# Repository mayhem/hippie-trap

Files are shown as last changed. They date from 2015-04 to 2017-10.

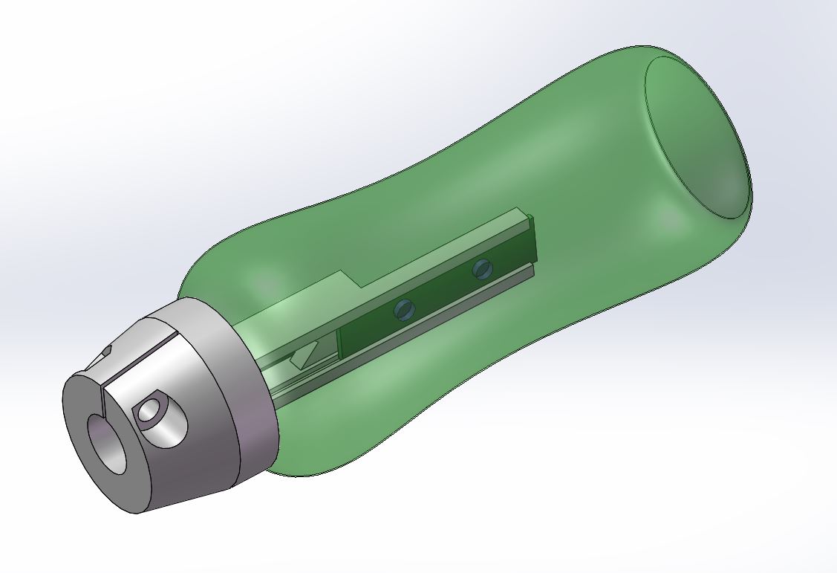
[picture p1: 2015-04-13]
design/bottle-light-assembly-1.jpg

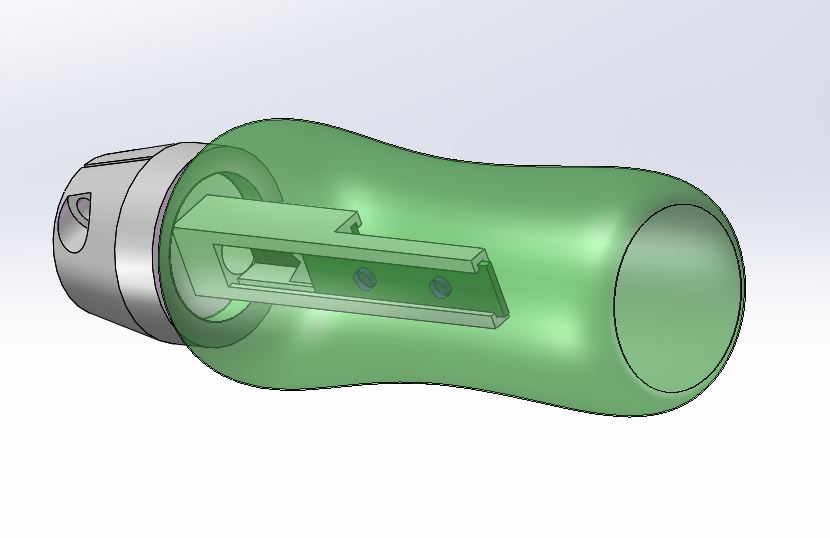
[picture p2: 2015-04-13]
design/bottle-light-assembly-2.jpg

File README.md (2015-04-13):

# led-chandelier
LED bottle chandelier built for Nowhere 2015

by Robert Kaye and David Martin

Mock-up
=======

For a render of what we think this might look like a look in the design folder.

Hardware notes
==============

The chandalier made up of about 100 bottles that will have circuit boards with LEDs
inside them. 4 RGD LEDs (WS2812B) connected to an atmega128 will light up each bottle.
Communication happens over a bone simple serial connection, hopefully at 250kbps.
For serial timing and ram reasons, I chose the atmega128 over the attiny84.

The bottles will be connected to 5V power, ground and a communication line. The communication
will be via a line driver that broadcasts the serial signal to each bottle. The RPi can then
send either color information to each bottle or more interestingly send a crude set of instructions
on how to build a color animation. This way the chanelier can work in a centrally coordinated
mode or each bottle carrying out its own program.

.brd and .sch files for Eagle are in hardware folder.

Notes about the circuit
-----------------------

- Regulated 5V power supply in the body of the chandelier
- WS2812B LEDS: http://www.adafruit.com/datasheets/WS2812B.pdf
- MCU: atmega168
- Shottky diodes on the inputs.
- Program via a pogoplug, no actual connector will be on the board.

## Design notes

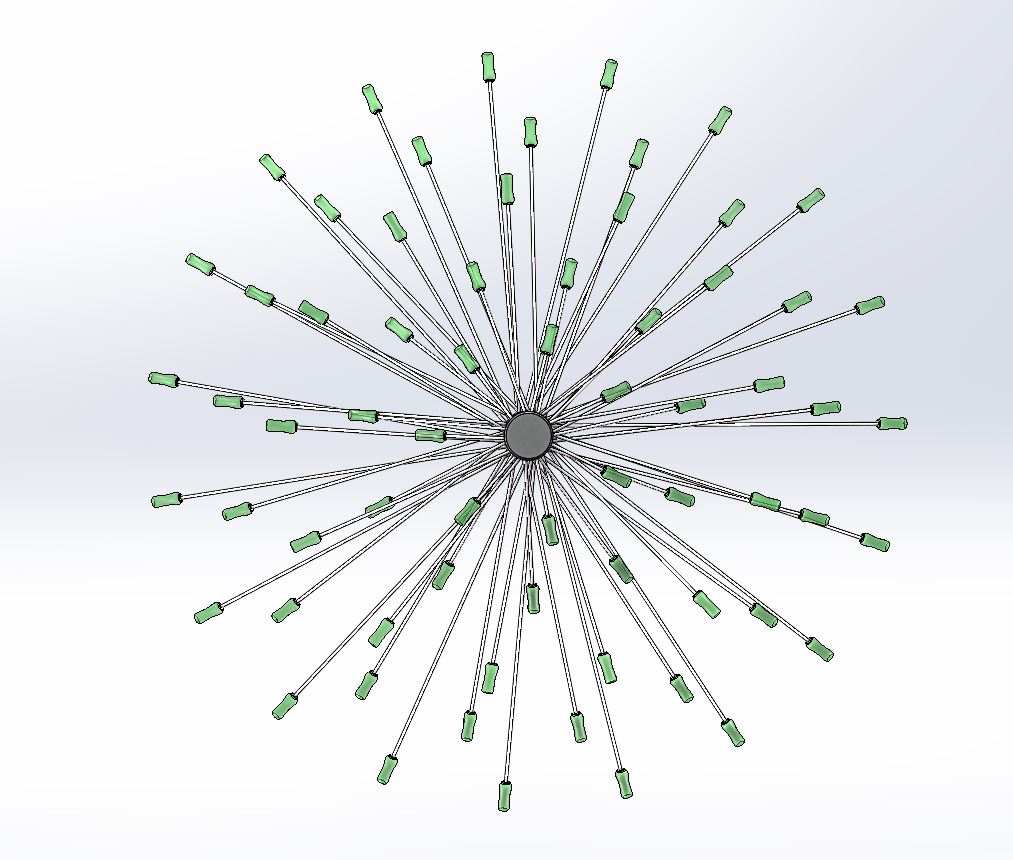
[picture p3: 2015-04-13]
design/chandelier-bottom-view.jpg

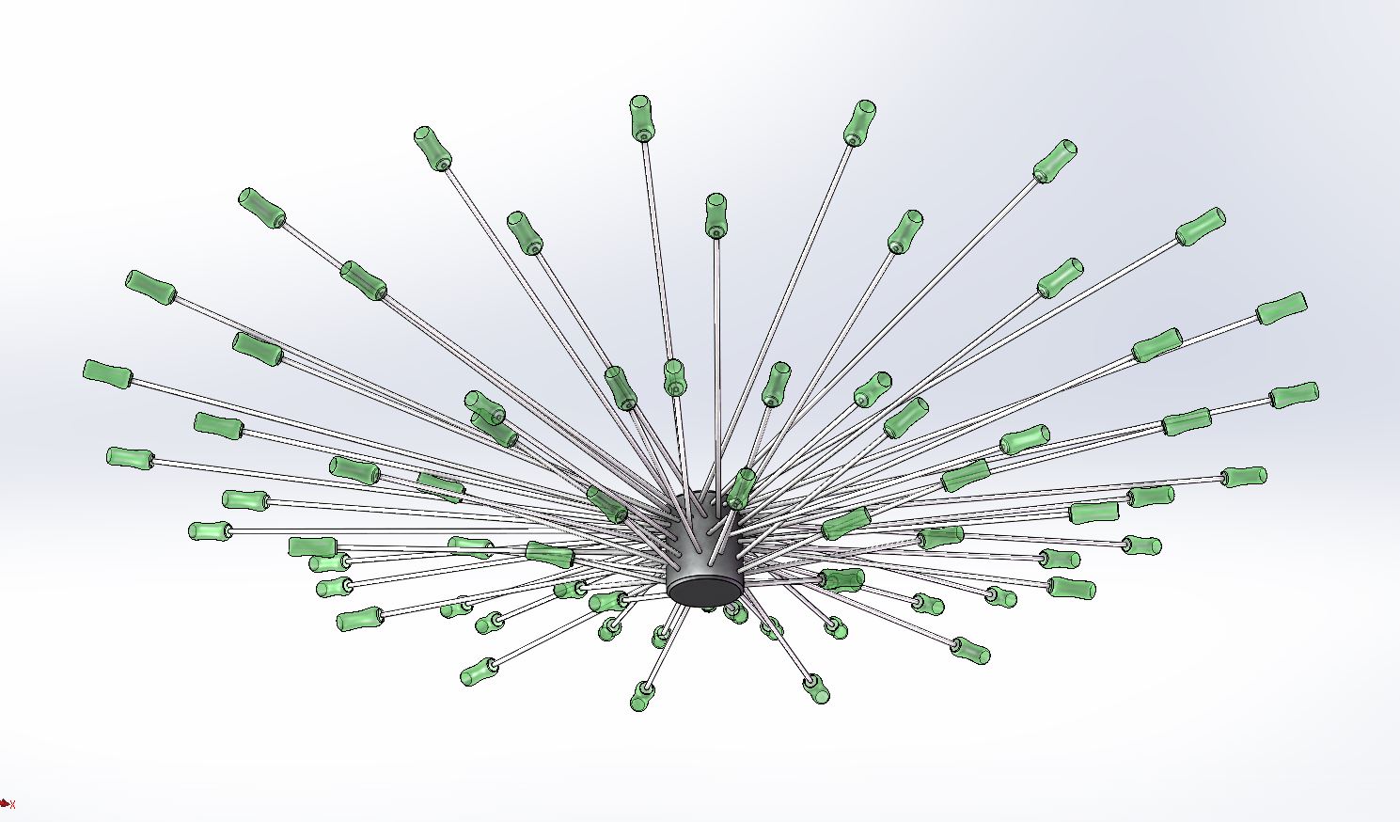
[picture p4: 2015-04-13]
design/chandelier-perspective-view.jpg

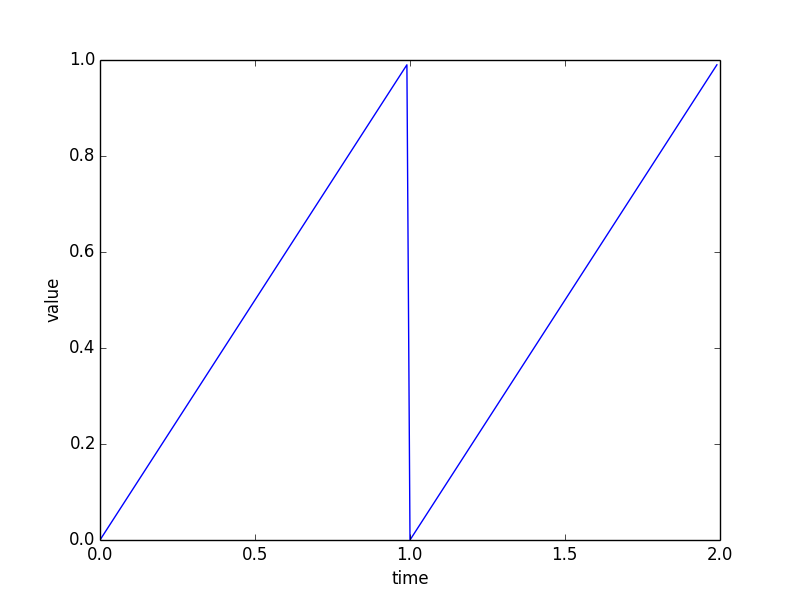
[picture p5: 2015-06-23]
graphs/sawtooth.png

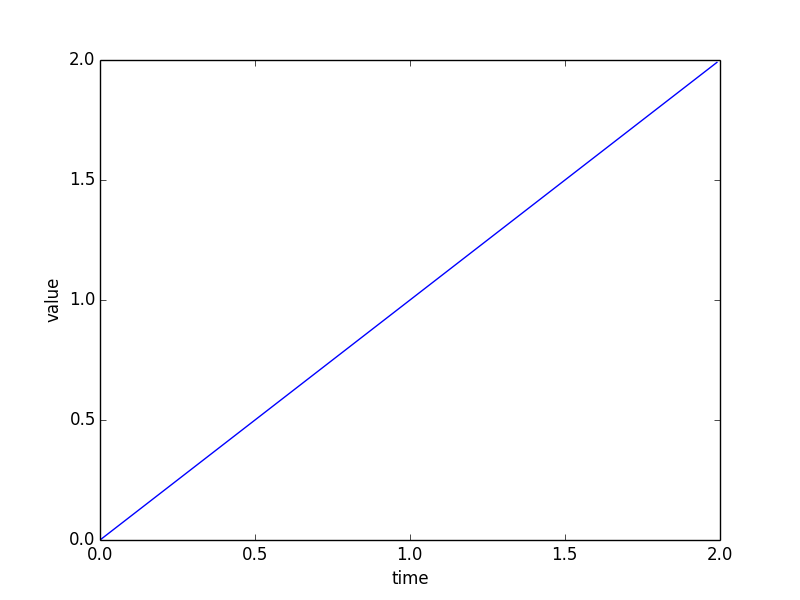
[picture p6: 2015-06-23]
graphs/line.png

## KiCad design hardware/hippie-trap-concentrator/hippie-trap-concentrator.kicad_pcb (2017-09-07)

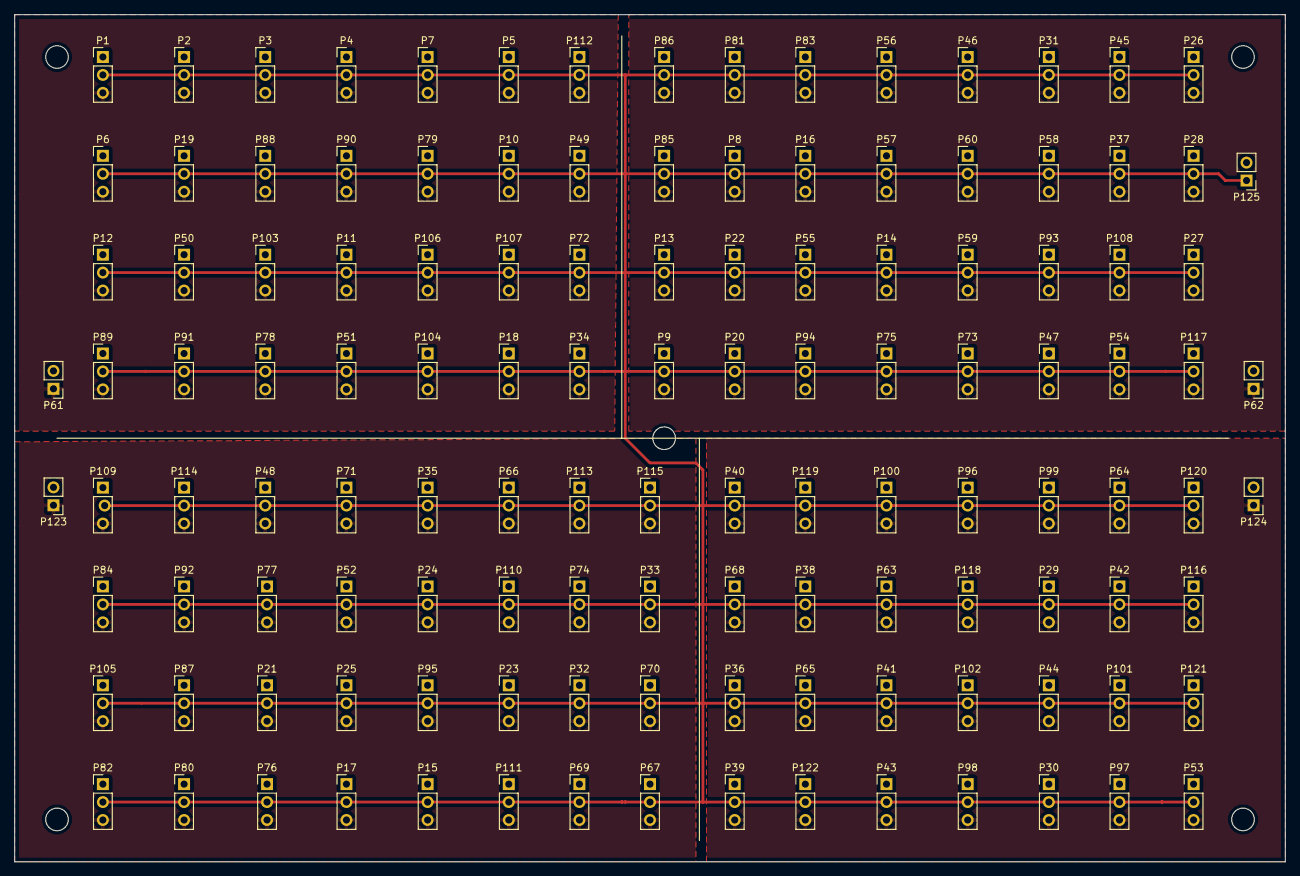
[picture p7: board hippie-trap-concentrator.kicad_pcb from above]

Board: 2 copper layers, 180.0 x 120.0 mm, 125 parts (0 on the bottom side), 3 nets.

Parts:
P1, P2, P3, P4, P5, P6, P7, P8, P9, P10, P11, P12, P13, P14, P15, P16, P17, P18, P19, P20, P21, P22, P23, P24, P25, P26, P27, P28, P29, P30, P31, P32, P33, P34, P35, P36, P37, P38, P39, P40, P41, P42, P43, P44, P45, P46, P47, P48, P49, P50, P51, P52, P53, P54, P55, P56, P57, P58, P59, P60, P63, P64, P65, P66, P67, P68, P69, P70, P71, P72, P73, P74, P75, P76, P77, P78, P79, P80, P81, P82, P83, P84, P85, P86, P87, P88, P89, P90, P91, P92, P93, P94, P95, P96, P97, P98, P99, P100, P101, P102, P103, P104, P105, P106, P107, P108, P109, P110, P111, P112, P113, P114, P115, P116, P117, P118, P119, P120, P121, P122: CONN_01X03; Pin_Header_Straight_1x03_Pitch2.54mm
P61: PWR1; Pin_Header_Straight_1x02_Pitch2.54mm
P62: PWR2; Pin_Header_Straight_1x02_Pitch2.54mm
P123: PWR3; Pin_Header_Straight_1x02_Pitch2.54mm
P124: PWR4; Pin_Header_Straight_1x02_Pitch2.54mm
P125: RPi; Pin_Header_Straight_1x02_Pitch2.54mm

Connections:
/5V: P1.3, P2.3, P3.3, P4.3, P5.3, P6.3, P7.3, P8.3, P9.3, P10.3, P11.3, P12.3, P13.3, P14.3, P15.3, P16.3, P17.3, P18.3, P19.3, P20.3, P21.3, P22.3, P23.3, P24.3, P25.3, P26.3, P27.3, P28.3, P29.3, P30.3, P31.3, P32.3, P33.3, P34.3, P35.3, P36.3, P37.3, P38.3, P39.3, P40.3, P41.3, P42.3, P43.3, P44.3, P45.3, P46.3, P47.3, P48.3, P49.3, P50.3, P51.3, P52.3, P53.3, P54.3, P55.3, P56.3, P57.3, P58.3, P59.3, P60.3, P61.1, P62.1, P63.3, P64.3, P65.3, P66.3, P67.3, P68.3, P69.3, P70.3, P71.3, P72.3, P73.3, P74.3, P75.3, P76.3, P77.3, P78.3, P79.3, P80.3, P81.3, P82.3, P83.3, P84.3, P85.3, P86.3, P87.3, P88.3, P89.3, P90.3, P91.3, P92.3, P93.3, P94.3, P95.3, P96.3, P97.3, P98.3, P99.3, P100.3, P101.3, P102.3, P103.3, P104.3, P105.3, P106.3, P107.3, P108.3, P109.3, P110.3, P111.3, P112.3, P113.3, P114.3, P115.3, P116.3, P117.3, P118.3, P119.3, P120.3, P121.3, P122.3, P123.1, P124.1
/DATA: P1.2, P2.2, P3.2, P4.2, P5.2, P6.2, P7.2, P8.2, P9.2, P10.2, P11.2, P12.2, P13.2, P14.2, P15.2, P16.2, P17.2, P18.2, P19.2, P20.2, P21.2, P22.2, P23.2, P24.2, P25.2, P26.2, P27.2, P28.2, P29.2, P30.2, P31.2, P32.2, P33.2, P34.2, P35.2, P36.2, P37.2, P38.2, P39.2, P40.2, P41.2, P42.2, P43.2, P44.2, P45.2, P46.2, P47.2, P48.2, P49.2, P50.2, P51.2, P52.2, P53.2, P54.2, P55.2, P56.2, P57.2, P58.2, P59.2, P60.2, P63.2, P64.2, P65.2, P66.2, P67.2, P68.2, P69.2, P70.2, P71.2, P72.2, P73.2, P74.2, P75.2, P76.2, P77.2, P78.2, P79.2, P80.2, P81.2, P82.2, P83.2, P84.2, P85.2, P86.2, P87.2, P88.2, P89.2, P90.2, P91.2, P92.2, P93.2, P94.2, P95.2, P96.2, P97.2, P98.2, P99.2, P100.2, P101.2, P102.2, P103.2, P104.2, P105.2, P106.2, P107.2, P108.2, P109.2, P110.2, P111.2, P112.2, P113.2, P114.2, P115.2, P116.2, P117.2, P118.2, P119.2, P120.2, P121.2, P122.2, P125.1
/GND: P1.1, P2.1, P3.1, P4.1, P5.1, P6.1, P7.1, P8.1, P9.1, P10.1, P11.1, P12.1, P13.1, P14.1, P15.1, P16.1, P17.1, P18.1, P19.1, P20.1, P21.1, P22.1, P23.1, P24.1, P25.1, P26.1, P27.1, P28.1, P29.1, P30.1, P31.1, P32.1, P33.1, P34.1, P35.1, P36.1, P37.1, P38.1, P39.1, P40.1, P41.1, P42.1, P43.1, P44.1, P45.1, P46.1, P47.1, P48.1, P49.1, P50.1, P51.1, P52.1, P53.1, P54.1, P55.1, P56.1, P57.1, P58.1, P59.1, P60.1, P61.2, P62.2, P63.1, P64.1, P65.1, P66.1, P67.1, P68.1, P69.1, P70.1, P71.1, P72.1, P73.1, P74.1, P75.1, P76.1, P77.1, P78.1, P79.1, P80.1, P81.1, P82.1, P83.1, P84.1, P85.1, P86.1, P87.1, P88.1, P89.1, P90.1, P91.1, P92.1, P93.1, P94.1, P95.1, P96.1, P97.1, P98.1, P99.1, P100.1, P101.1, P102.1, P103.1, P104.1, P105.1, P106.1, P107.1, P108.1, P109.1, P110.1, P111.1, P112.1, P113.1, P114.1, P115.1, P116.1, P117.1, P118.1, P119.1, P120.1, P121.1, P122.1, P123.2, P124.2, P125.2

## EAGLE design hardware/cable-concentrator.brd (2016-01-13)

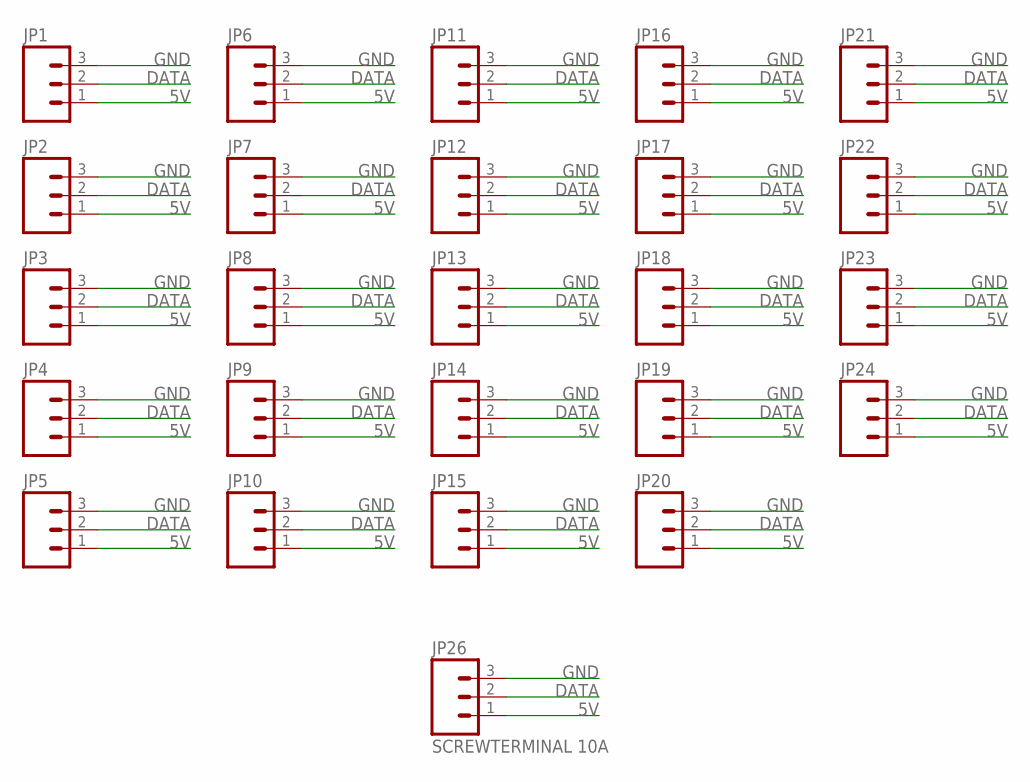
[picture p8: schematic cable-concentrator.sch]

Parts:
JP1, JP2, JP3, JP4, JP5, JP6, JP7, JP8, JP9, JP10, JP11, JP12, JP13, JP14, JP15, JP16, JP17, JP18, JP19, JP20, JP21, JP22, JP23, JP24: M03PTH; 1X03
JP26: SCREWTERMINAL 10A; SCREWTERMINAL-3.5MM-3

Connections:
5V: JP1.1, JP2.1, JP3.1, JP4.1, JP5.1, JP6.1, JP7.1, JP8.1, JP9.1, JP10.1, JP11.1, JP12.1, JP13.1, JP14.1, JP15.1, JP16.1, JP17.1, JP18.1, JP19.1, JP20.1, JP21.1, JP22.1, JP23.1, JP24.1, JP26.1
DATA: JP1.2, JP2.2, JP3.2, JP4.2, JP5.2, JP6.2, JP7.2, JP8.2, JP9.2, JP10.2, JP11.2, JP12.2, JP13.2, JP14.2, JP15.2, JP16.2, JP17.2, JP18.2, JP19.2, JP20.2, JP21.2, JP22.2, JP23.2, JP24.2, JP26.2
GND: JP1.3, JP2.3, JP3.3, JP4.3, JP5.3, JP6.3, JP7.3, JP8.3, JP9.3, JP10.3, JP11.3, JP12.3, JP13.3, JP14.3, JP15.3, JP16.3, JP17.3, JP18.3, JP19.3, JP20.3, JP21.3, JP22.3, JP23.3, JP24.3, JP26.3

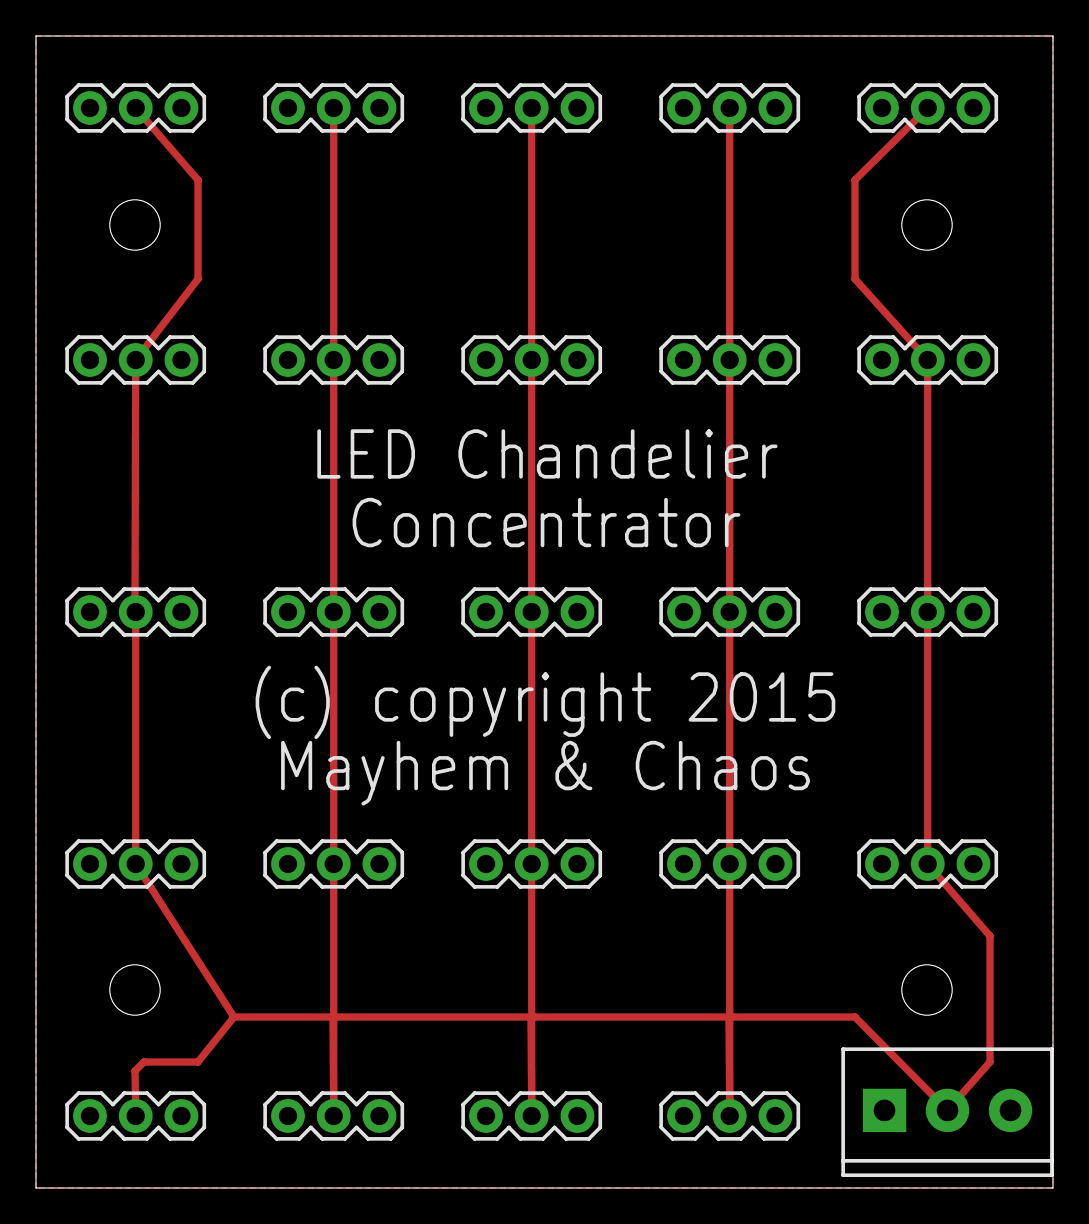
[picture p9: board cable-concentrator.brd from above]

Board: 2 copper layers, 56.5 x 64.0 mm, 25 parts (0 on the bottom side), 3 nets.

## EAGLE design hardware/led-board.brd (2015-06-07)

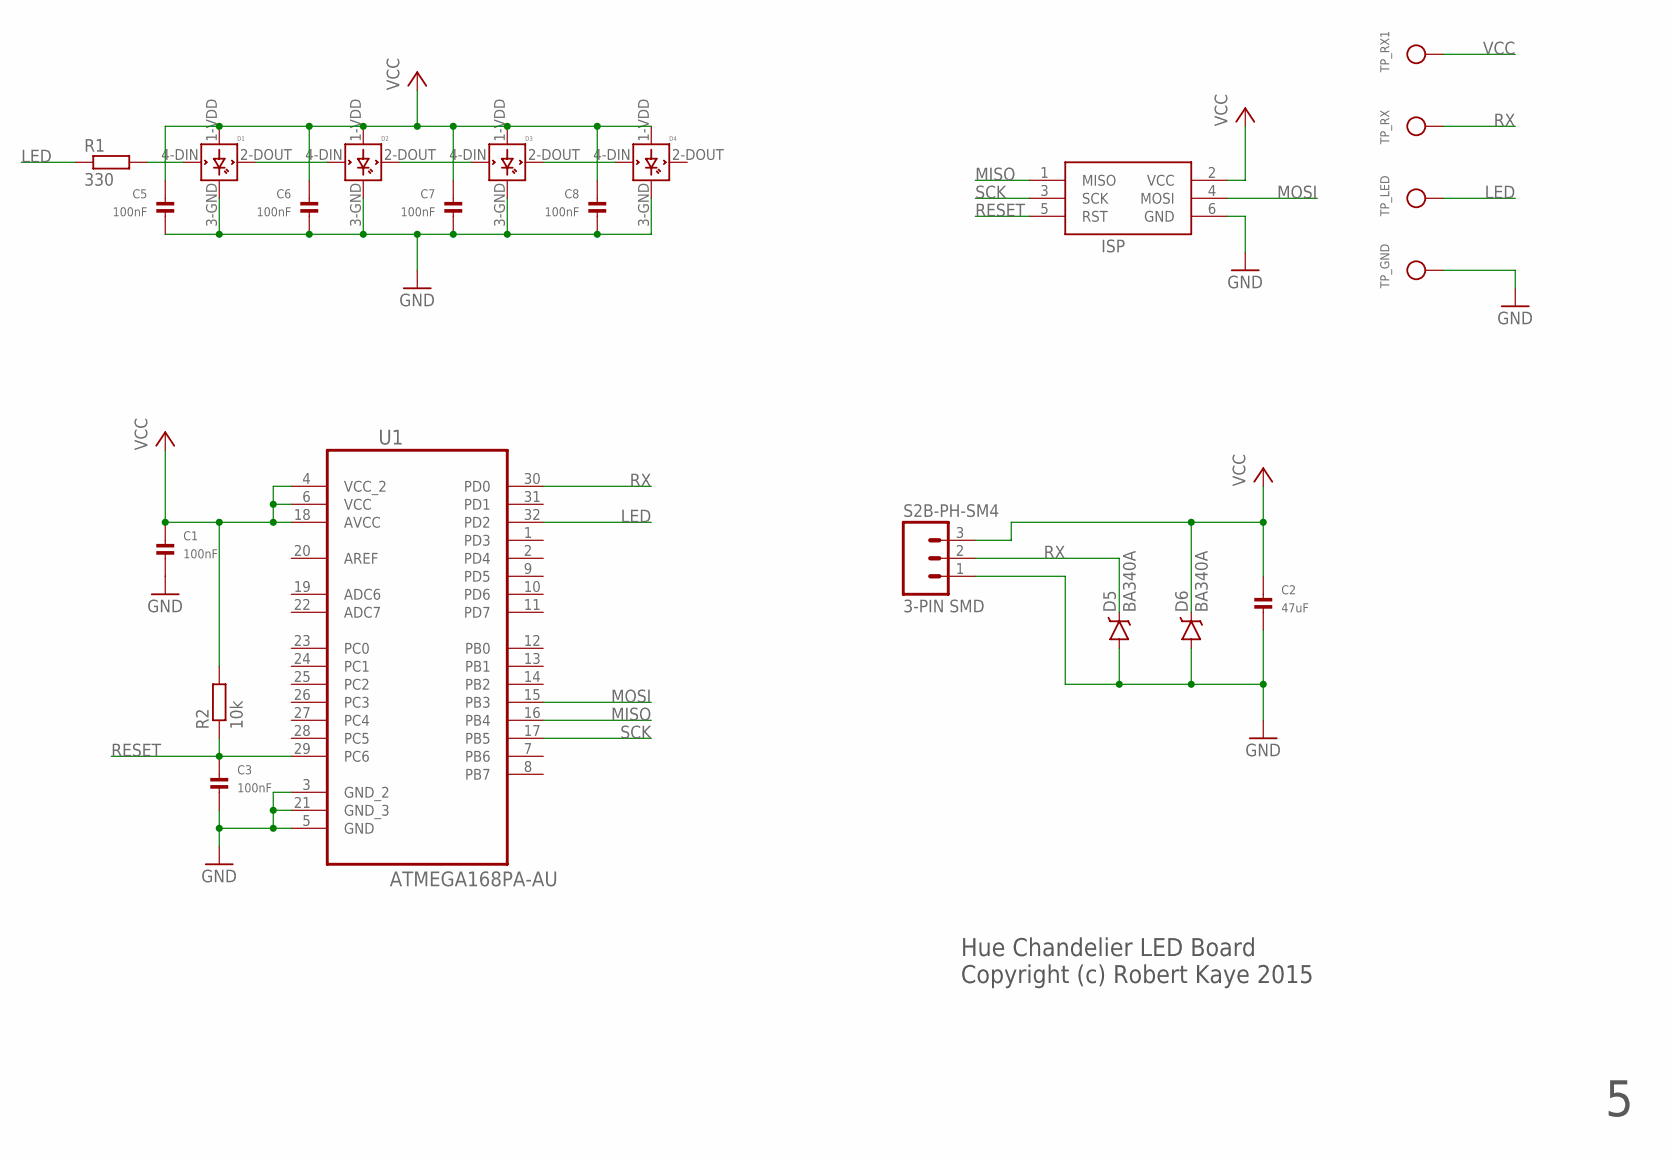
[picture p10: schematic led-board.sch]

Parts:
C1, C3, C5, C6, C7, C8: 100nF; 0805; MPN MCSH21B104K250CT
C2: 47uF; 1206; MPN CC0805KKX7R7BB105
D1, D2, D3, D4: WS2812B; MPN WS2812B
D5, D6: BA340A; SMA-DIODE; MPN B330A-13-F
ISP: AVRISP-6; AVRISP
R1: 330; R0805; MPN RC0805JR-07330RL
R2: 10k; R0805; MPN RT0805FRE0710KL
S2B-PH-SM4: 3-PIN SMD; JST-3-SMD; MPN S3B-PH-SM4-TB(LF)(SN)
TP_GND: TESTPOINT1.5X2.0MM_NOCREAM; PAD-1.5X2.0
TP_LED: TESTPOINT1.5X2.0MM_NOCREAM; PAD-1.5X2.0
TP_RX, TP_RX1: TESTPOINT1.5X2.0MM_NOCREAM; PAD-1.5X2.0
U1: ATMEGA168PA-AU; QFP80P900X900X120-32N

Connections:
D3: D2.2-DOUT (DOUT), D3.4-DIN (DIN)
GND: C1.2, C2.2, C3.2, C5.2, C6.2, C7.2, C8.2, D1.3-GND (GND), D2.3-GND (GND), D3.3-GND (GND), D4.3-GND (GND), D5.A, D6.A, ISP.6 (GND), S2B-PH-SM4.1, TP_GND.P$1, U1.3 (GND_2), U1.5 (GND), U1.21 (GND_3)
LED: R1.1, TP_LED.P$1, U1.32 (PD2)
MISO: ISP.1 (MISO), U1.16 (PB4)
MOSI: ISP.4 (MOSI), U1.15 (PB3)
unnamed: D3.2-DOUT (DOUT), D4.4-DIN (DIN)
unnamed: D1.2-DOUT (DOUT), D2.4-DIN (DIN)
unnamed: D1.4-DIN (DIN), R1.2
RESET: C3.1, ISP.5 (RST), R2.1, U1.29 (PC6)
RX: D5.C, S2B-PH-SM4.2, TP_RX.P$1, U1.30 (PD0)
SCK: ISP.3 (SCK), U1.17 (PB5)
VCC: C1.1, C2.1, C5.1, C6.1, C7.1, C8.1, D1.1-VDD (VDD), D2.1-VDD (VDD), D3.1-VDD (VDD), D4.1-VDD (VDD), D6.C, ISP.2 (VCC), R2.2, S2B-PH-SM4.3, TP_RX1.P$1, U1.4 (VCC_2), U1.6 (VCC), U1.18 (AVCC)

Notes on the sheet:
Hue Chandelier LED Board Copyright (c) Robert Kaye 2015

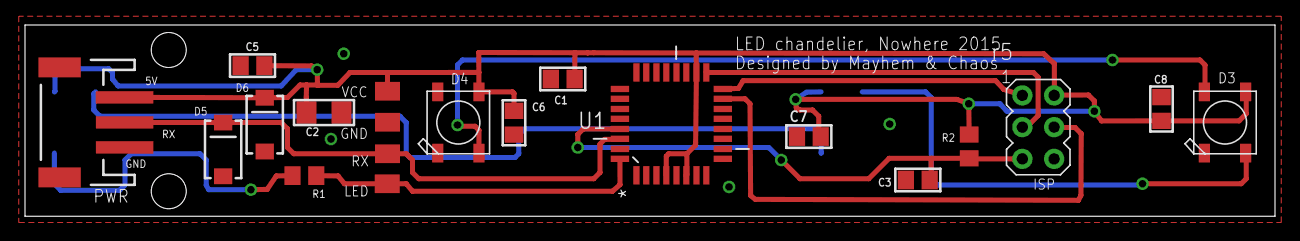
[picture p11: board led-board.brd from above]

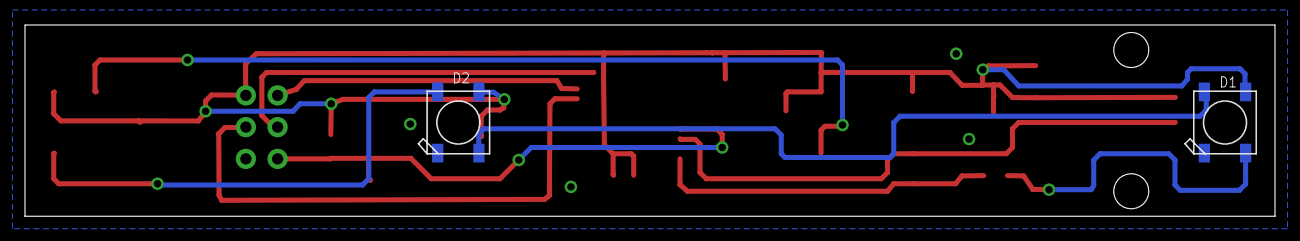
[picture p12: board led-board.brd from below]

Board: 2 copper layers, 100.0 x 15.3 mm, 22 parts (2 on the bottom side), 12 nets.

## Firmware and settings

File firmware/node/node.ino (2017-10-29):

#include <TimerOne.h>

#include <util/crc16.h>
#include <EEPROM.h>
#include <Adafruit_NeoPixel.h>
#include <avr/pgmspace.h>
#include <avr/wdt.h>
#include <stdarg.h>
#include "parse.h"

const uint8_t NODE_ID_UNKNOWN = 255;
const uint8_t MAX_NODES = 120;
const uint8_t OUT_PIN = 2;
const uint8_t US_PER_TICK = 25;

const uint16_t MAX_PACKET_LEN     = 230;
const uint8_t BROADCAST = 0;
const uint8_t PACKET_SET_ID       = 0;
const uint8_t PACKET_CLEAR_ID     = 1; 
const uint8_t PACKET_SINGLE_COLOR = 2; 
const uint8_t PACKET_COLOR_ARRAY  = 3; 
const uint8_t PACKET_PATTERN      = 4; 
const uint8_t PACKET_ENTROPY      = 5; 
const uint8_t PACKET_START        = 6; 
const uint8_t PACKET_OFF          = 7; 
const uint8_t PACKET_CLEAR_NEXT   = 8; 
const uint8_t PACKET_POSITION     = 9; 
const uint8_t PACKET_DELAY        = 10;
const uint8_t PACKET_ADDR         = 11;
const uint8_t PACKET_SPEED        = 12;
const uint8_t PACKET_CLASSES      = 13;
const uint8_t PACKET_CALIBRATE    = 14;
const uint8_t PACKET_BRIGHTNESS   = 15;
const uint8_t PACKET_ANGLE        = 16;
const uint8_t PACKET_BOOTLOADER   = 17;

// where in EEPROM our node id is stored. The first 16 are reserved for the bootloader
// Bootloader items
const uint8_t ee_start_program_offset       = 0;
const uint8_t ee_have_valid_program_offset  = 1;
const uint8_t ee_program_version_offset     = 2;

// Node items
const uint8_t ee_id_offset                  = 16;
const uint8_t ee_calibration_offset         = 17;

// ----- globals ------------
uint8_t    g_error = ERR_OK;

// time keeping
uint32_t   g_target = 0;
uint8_t    g_delay = 10;
uint32_t   g_speed = SCALE_FACTOR;
uint32_t   g_ticks_per_sec = (int32_t)1000000 / US_PER_TICK;
uint32_t   g_ticks_per_frame; // setup later

// random seed
uint32_t    g_random_seed = 0;

// pattern, packet, heap
uint8_t     g_pattern_active = 0;
uint8_t     g_have_valid_pattern = 0;
pattern_t   g_pattern;
uint8_t     g_packet[MAX_PACKET_LEN];
uint8_t     g_heap[HEAP_SIZE];

// The LED control object
Adafruit_NeoPixel g_pixels = Adafruit_NeoPixel(NUM_PIXELS, OUT_PIN, NEO_GRB + NEO_KHZ800);

// our node id
uint8_t g_node_id = 0;

// color/step information for transitions
color_t  g_color[NUM_PIXELS];
int32_t  g_brightness;

// location in space
int16_t g_pos[3];
int32_t g_angle;

// broadcast classes
const uint8_t NUM_CLASSES = 16;
const uint8_t NO_CLASS = 255;
uint8_t g_classes[NUM_CLASSES];

// calibration values
uint8_t  g_calibrate = 0; // stores the duration of the calibration in seconds
uint32_t g_calibrate_start = 0;


// Gamma correction table in progmem
const uint8_t PROGMEM gamma[] = {
    0,  0,  0,  0,  0,  0,  0,  0,  0,  0,  0,  0,  0,  0,  0,  0,
    0,  0,  0,  0,  0,  0,  0,  0,  0,  0,  0,  0,  1,  1,  1,  1,
    1,  1,  1,  1,  1,  1,  1,  1,  1,  2,  2,  2,  2,  2,  2,  2,
    2,  3,  3,  3,  3,  3,  3,  3,  4,  4,  4,  4,  4,  5,  5,  5,
    5,  6,  6,  6,  6,  7,  7,  7,  7,  8,  8,  8,  9,  9,  9, 10,
   10, 10, 11, 11, 11, 12, 12, 13, 13, 13, 14, 14, 15, 15, 16, 16,
   17, 17, 18, 18, 19, 19, 20, 20, 21, 21, 22, 22, 23, 24, 24, 25,
   25, 26, 27, 27, 28, 29, 29, 30, 31, 32, 32, 33, 34, 35, 35, 36,
   37, 38, 39, 39, 40, 41, 42, 43, 44, 45, 46, 47, 48, 49, 50, 50,
   51, 52, 54, 55, 56, 57, 58, 59, 60, 61, 62, 63, 64, 66, 67, 68,
   69, 70, 72, 73, 74, 75, 77, 78, 79, 81, 82, 83, 85, 86, 87, 89,
   90, 92, 93, 95, 96, 98, 99,101,102,104,105,107,109,110,112,114,
  115,117,119,120,122,124,126,127,129,131,133,135,137,138,140,142,
  144,146,148,150,152,154,156,158,160,162,164,167,169,171,173,175,
  177,180,182,184,186,189,191,193,196,198,200,203,205,208,210,213,
  215,218,220,223,225,228,231,233,236,239,241,244,247,249,252,255 
};

// ---- prototypes -----
void next_pattern(void);  

volatile uint32_t g_time = 0;
void tick(void)
{
    g_time++;
}

void reset_ticks(void)
{
    noInterrupts();
    g_time = 0;
    interrupts();
}

uint32_t ticks(void)
{
    uint32_t temp;

    noInterrupts();
    temp = g_time;
    interrupts();

    return temp; 
}

uint32_t ticks_to_ms(uint32_t ticks)
{
    return ticks * SCALE_FACTOR / g_ticks_per_sec;
}

void show_color(color_t *col)
{
    uint8_t j;
   
    for(j = 0; j < NUM_PIXELS; j++)
        set_pixel_color(j, col);

    g_pixels.show();
}

void set_pixel_color(uint8_t index, color_t *col)
{
    color_t temp;

    if (!col)
    {
        temp.c[0] = 0;
        temp.c[1] = 0;
        temp.c[2] = 0;
    }
    else
    {
        // Color correct
        temp.c[0] = pgm_read_byte(&gamma[col->c[0]]);
        temp.c[1] = pgm_read_byte(&gamma[col->c[1]]);
        temp.c[2] = pgm_read_byte(&gamma[col->c[2]]);

        // Adjust brightness
        temp.c[0] = temp.c[0] * g_brightness / SCALE_FACTOR;
        temp.c[1] = temp.c[1] * g_brightness / SCALE_FACTOR;
        temp.c[2] = temp.c[2] * g_brightness / SCALE_FACTOR;
    }

    g_pixels.setPixelColor(index, temp.c[0], temp.c[1], temp.c[2]);
    g_color[index] = temp;
}

void startup_animation(void)
{
    uint8_t i, j;
    color_t col1, col2;

    col1.c[0] = 255;
    col1.c[1] = 140;
    col1.c[2] = 0;
    col2.c[0] = 255;
    col2.c[1] = 0;
    col2.c[2] = 255;

    for(i = 0; i < 10; i++)
    {       
        for(j = 0; j < NUM_PIXELS; j++)
        {
            if (i % 2 == 0)
            {
                if (j % 2 == 1)
                    set_pixel_color(j, &col1);
                else
                    set_pixel_color(j, NULL);
            }
            else
            {
                if (j % 2 == 0)
                    set_pixel_color(j, &col2);
                else
                    set_pixel_color(j, NULL);  
            }
        }   
        g_pixels.show();
        delay(100);
    }
    show_color(NULL);
}

void handle_packet(uint16_t len, uint8_t *packet)
{
    uint8_t    j, type, target;
    uint8_t   *data;

    target = packet[0];
    if (target >= MAX_NODES + 1)
    {
        uint8_t cls = target - (MAX_NODES + 1), i;

        for(i = 0; i < NUM_CLASSES; i++)
            if (g_classes[i] == cls)
            {
                target = g_node_id;
                break;
            }
    }

    if (target != BROADCAST && target != g_node_id)
        return;
      
    type = packet[1];
    data = &packet[2];
    switch(type)
    {
        case PACKET_SET_ID:
            {
                if (g_node_id == NODE_ID_UNKNOWN)
                {
                    g_node_id = data[0];
                    EEPROM.write(ee_id_offset, g_node_id);
                }
                break;
            }

        case PACKET_CLEAR_ID:
            {
                g_node_id = NODE_ID_UNKNOWN;
                EEPROM.write(ee_id_offset, g_node_id);
                break;
            }
            
        case PACKET_SINGLE_COLOR:
            {
                color_t col;
                col.c[0] = data[0];
                col.c[1] = data[1];
                col.c[2] = data[2];

                for(int j=0; j < NUM_PIXELS; j++)
                    show_color(&col);

                break;
            } 
        case PACKET_COLOR_ARRAY:
            {
                color_t col;

                for(int j=0; j < NUM_PIXELS; j++, data += 3)
                {
                    col.c[0] = data[0];
                    col.c[1] = data[1];
                    col.c[2] = data[2];
                    set_pixel_color(j, &col);
                }
                g_pixels.show();
                break;  
            }
            
        case PACKET_PATTERN:
            {
                g_pattern_active = 0;

                // reset the heap, thereby destroying the previous patten object
                heap_setup(g_heap);

                if (parse_packet(data, len - 2, &g_pattern))
                {
                    dprintf("parse ok\n");
                    g_have_valid_pattern = 1;
                }                    
                break;  
            }

        case PACKET_START:
            {
                dprintf("Received start\n");
                start_pattern();
                break;
            }
            
        case PACKET_OFF:
            {
                g_pattern_active = 0;
                g_error = ERR_OK;
                g_target = 0;
                set_brightness(1000);
                show_color(NULL);
            }
            break;
            
        case PACKET_ENTROPY:
            {
                color_t col;

                g_random_seed = *(int32_t *)data;
                randomSeed(g_random_seed);
                show_color(NULL);
            }
            break;  

        case PACKET_DELAY:
            g_delay = data[0];
            break;  

        case PACKET_SPEED:
            g_speed = *(uint16_t *)data;
            break;  
            
        case PACKET_POSITION:
        { 
            g_pos[0] = *(uint16_t *)data;
            g_pos[1] = *(uint16_t *)(&data[2]);
            g_pos[2] = *(uint16_t *)(&data[4]);
            break;       
        }

        case PACKET_ANGLE:
        { 
            g_angle = *(uint32_t *)data;
            break;       
        }

        case PACKET_CLASSES:
            {
                uint8_t i;

                for(i = 0; i < NUM_CLASSES; i++)
                    g_classes[i] = NO_CLASS;

                for(i = 0; i < len - 2; i++)
                    g_classes[i] = data[i];

                break;
            }
        case PACKET_CALIBRATE:
            {  
                color_t col;

                col.c[1] = col.c[2] = 0;
                col.c[0] = 255;

                // clear out any stray characters
                while(Serial.available() > 0) 
                    Serial.read();

                show_color(&col);
                reset_ticks();
                g_calibrate = data[0];
                g_calibrate_start = 0;
                break;
            }
        case PACKET_BRIGHTNESS:
            {
                int32_t b;
                b = (int32_t)data[0] * 10;
                set_brightness(b);
                break;
            }
        case PACKET_BOOTLOADER:
            {
                EEPROM.write(ee_start_program_offset, 0);
                wdtreset();
            }
        default:
            dprintf("Invalid packet received\n");
    }
}

#if 0
void print_col(color_t *c)
{
    Serial.print(c->c[0], DEC);
    Serial.print(", ");
    Serial.print(c->c[1], DEC);
    Serial.print(", ");
    Serial.println(c->c[2], DEC);
}
#endif

void set_brightness(int32_t brightness)
{
    g_brightness = brightness;
}

void start_pattern(void)
{
    uint8_t  i;
    color_t     color;

    if (!g_have_valid_pattern)
        return;

    reset_ticks();
    g_target = g_ticks_per_frame;
    g_error = ERR_OK;
    g_pattern_active = 1;
    g_have_valid_pattern = 0;

    update_pattern();  
}    

void update_pattern(void)
{
    uint8_t  i;
    color_t  color;

    if (g_error)
    {
        error_pattern();
        return;
    }

    if (!g_pattern_active)
        return;

    if (g_target && ticks() >= g_target)
    {
        g_target += g_ticks_per_frame;
        g_pixels.show();

        for(i = 0; i < NUM_PIXELS; i++)
        {
            color = g_color[i];
            evaluate(&g_pattern, ticks_to_ms(g_target), i, &color);
            set_pixel_color(i, &color);
        }
    }
}

void error_pattern(void)
{
    uint8_t  t;
    uint8_t  i;
    color_t  col;

    t = ticks_to_ms(ticks()) % (ERROR_DELAY * 2);
    if (t > ERROR_DELAY)
    {
        switch(g_error)
        {
            case ERR_NO_VALID_PATTERN: // orange
                 col.c[0] = 128;
                 col.c[1] = 40;
                 col.c[0] = 0;
                 break;

            case ERR_STACK_CLASH:  // red
                 col.c[0] = 255;
                 col.c[1] = col.c[2] = 0;
                 break;

            case ERR_OUT_OF_HEAP:  // green
                 col.c[1] = 255;
                 col.c[0] = col.c[2] = 0;
                 break;

            case ERR_PARSE_FAILURE:  // blue
                 col.c[2] = 255;
                 col.c[0] = col.c[1] = 0;
                 break;

            default:    
                 col.c[0] = 128;
                 col.c[1] = 0;
                 col.c[2] = 128;
                 break;
        }
        show_color(&col);
    }
    else
        show_color(NULL);
}

#define MAX 80 
void dprintf(const char *fmt, ...)
{
    va_list va;
    va_start (va, fmt);

    char buffer[MAX];
    char *ptr = buffer;
    vsnprintf(buffer, MAX, fmt, va);
    va_end (va);

    for(ptr = buffer; *ptr; ptr++)
    {
       if (*ptr == '\n') 
           Serial.write('\r');
       Serial.write(*ptr);
    }
}

void setup()
{ 
    uint32_t timer_cal;
    color_t col;
    uint8_t i, valid_program;

    // Tell the bootloader that we ran, if we haven't before.
    EEPROM.get(ee_have_valid_program_offset, valid_program);
    if (!valid_program)
        EEPROM.write(ee_have_valid_program_offset, 1);

    Serial.begin(38400);
    Serial.println("hippie-trap led board!\n");

    g_pixels.begin();
    startup_animation();
        
    g_node_id = EEPROM.read(ee_id_offset);

    EEPROM.get(ee_calibration_offset, timer_cal);
    if (timer_cal > 1 && timer_cal != 0xFFFF)
    {
        g_ticks_per_sec = timer_cal;
        Serial.print("calibrated " + String(timer_cal) + " ");
        col.c[0] = 0;
        col.c[1] = 128;
        col.c[2] = 0;
    }
    else
    {
        col.c[0] = 0;
        col.c[1] = 0;
        col.c[2] = 128;
    }
    if (g_node_id == 0 || g_node_id >= MAX_NODES)
    {
        col.c[0] = 128;
        col.c[1] = 0;
        col.c[2] = 0;
    }
    show_color(&col);

    Serial.println("node " + String(g_node_id) + " ready. ");

    g_ticks_per_frame = g_ticks_per_sec * g_delay / 1000;

    memset(&g_pattern, 0, sizeof(pattern_t));
    memset(&g_color, 0, sizeof(g_color));

    Timer1.initialize(US_PER_TICK);
    Timer1.attachInterrupt(tick);
    
    for(i = 0; i < NUM_CLASSES; i++)
        g_classes[i] = NO_CLASS;

}

void loop()
{
    uint8_t            i, ch, data[3];
    static uint8_t     found_header = 0;
    static uint16_t    crc = 0, len = 0, recd = 0;
    
    if (g_calibrate)
    {
        if (Serial.available() > 0 && g_calibrate_start == 0)
        {
             noInterrupts();
             g_calibrate_start = g_time;
             interrupts();
             Serial.read();
             
             return;
        }
        if (Serial.available() > 0 && g_calibrate_start > 0)
        {
             int32_t done, ticks_per_sec;
             noInterrupts();
             done = (int32_t)g_time;
             interrupts();
             
             show_color(NULL);

             g_ticks_per_sec = (done - g_calibrate_start) / g_calibrate;
             g_ticks_per_frame = g_ticks_per_sec * g_delay / 1000;
             EEPROM.put(ee_calibration_offset, g_ticks_per_sec);
             
             Serial.read();
                       
             g_calibrate = 0;
             g_calibrate_start = 0;
             
             return;
        }
        return;
    }
    
    update_pattern();
    
    if (Serial.available() > 0) 
    {
        ch = Serial.read();
        if (!found_header)
        {
            if (ch == 0xFF)
            {
                found_header = 1;
            }
        }
        else
        {
            if (!len)
            {
                // We just found the header, now a realistic packet size must follow
                if (ch > 0 && ch <= MAX_PACKET_LEN)
                {
                    len = ch;
                    recd = 0;
                }
                else
                    // Nope, that was no header, better keep looking.
                    found_header = 0;
            }
            else
            {
                g_packet[recd++] = ch;
                
                if (recd <= len - 2)
                    crc = _crc16_update(crc, ch);

                if (recd == len || recd == MAX_PACKET_LEN)
                {
                    uint16_t *pcrc;
                            
                            
                    // if we received the right length, check the crc. If that matches, we have a packet!
                    if (recd == len)
                    {            
                        pcrc = (uint16_t *)(g_packet + len - 2);
                        if (crc == *pcrc)
                            handle_packet(len - 2, g_packet);
                    }

                    len = 0;
                    crc = 0;
                    found_header = 0;
                    recd = 0;
                }
            }
        }
    }

}

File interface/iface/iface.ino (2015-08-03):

#include <CapacitiveSensor.h>

#define MAX_SENSORS 6

CapacitiveSensor cs0 = CapacitiveSensor(2,3);
CapacitiveSensor cs1 = CapacitiveSensor(4,5);
CapacitiveSensor cs2 = CapacitiveSensor(6,7);
CapacitiveSensor cs3 = CapacitiveSensor(8,9);
CapacitiveSensor cs4 = CapacitiveSensor(10,11);
CapacitiveSensor cs5 = CapacitiveSensor(12,13);
//CapacitiveSensor cs6 = CapacitiveSensor(14,15);
//CapacitiveSensor cs7 = CapacitiveSensor(16,17);
//CapacitiveSensor cs8 = CapacitiveSensor(18,19);

const long threshold = 700;
const long num = 6;
long states[MAX_SENSORS];

void setup() 
{
    uint8_t i;
    
    Serial.begin(9600);
    
    for(i = 0; i < MAX_SENSORS; i++)
        states[i] = 0;
    
    cs0.set_CS_AutocaL_Millis(0xFFFFFFFF);
    cs1.set_CS_AutocaL_Millis(0xFFFFFFFF);
    cs2.set_CS_AutocaL_Millis(0xFFFFFFFF);
    cs3.set_CS_AutocaL_Millis(0xFFFFFFFF);
    cs4.set_CS_AutocaL_Millis(0xFFFFFFFF);
    cs5.set_CS_AutocaL_Millis(0xFFFFFFFF);
    //cs6.set_CS_AutocaL_Millis(0xFFFFFFFF);
    //cs7.set_CS_AutocaL_Millis(0xFFFFFFFF);
    //cs8.set_CS_AutocaL_Millis(0xFFFFFFFF);
}

void check_sensor(uint8_t id, CapacitiveSensor *s)
{
    long total;
        
    total = s->capacitiveSensor(30);
    //if (total > 1000)
    //  Serial.println(total);
        
    if (total > threshold && states[id] == 0)
    {
        Serial.println(id);
        states[id] = 1;
    }
    if (total <= threshold && states[id] == 1)
        states[id] = 0;
        
}

void loop() 
{
    long total;
    
    delay(100);
    
    check_sensor(0, &cs0);
    if (num == 1)
        return;

    check_sensor(1, &cs1);
    if (num == 2)
        return;        

    check_sensor(2, &cs2);
    if (num == 3)
        return;

    check_sensor(3, &cs3);
    if (num == 4)
        return;

    check_sensor(4, &cs4);
    if (num == 5)
        return;

    check_sensor(5, &cs5);
    if (num == 6)
        return;     
#if 0
    check_sensor(6, &cs6);

    
    if (num == 7)
        return;

    check_sensor(7, &cs7);
    if (num == 8)
        return; 
        
    check_sensor(8, &cs8);
#endif
}

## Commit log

2015-04-09 Only darkness before this commit
    [led-board.brd, led-board.sch]
2015-04-09 Fully routed and it doesn't fully look like ass!
    [led-board.brd]
2015-04-09 Finished layout and silkscreen work
    [led-board.brd, led-board.sch]
2015-04-09 Approve one error after review
    [led-board.sch]
2015-04-11 Last version of the arduino code with nurfl stuff. New layout without nurfl.
    [led-board.brd, led-board.sch]
2015-04-11 Basic working node code, updated schematic and layout
    [led-board.brd, led-board.sch]
2015-04-13 Fixed the orientation of the shottky diodes, improved the layout a bit
    [led-board.brd, led-board.sch]
2015-04-13 Finished layot and silkscreening. Hopefully ready to go!
    [led-board.brd, led-board.sch]
2015-04-14 Updated based on Bernard's feedback: Moved parts from the back to the front and moved one via out from under the mcu. Also ensured that no parts are close to the edges.
    [led-board.brd, led-board.sch]
2015-04-14 Added mounting holes. Might be done now!
    [led-board.brd]
2015-04-14 Moved C7 further away from U1
    [led-board.brd]
2015-04-14 Increased bulk capacitance (C1) to 47uF.
    [led-board.brd, led-board.sch]
2015-04-14 Changed L# -> D# for the LEDs
    [led-board.brd, led-board.sch]
2015-04-16 Implemented filters and added FadeIn and FadeOut filter
2015-05-20 Added code to describe the parameters that need to be sent to the chandelier. Reworked an existing pattern to not use state or an external while loop. I understand functional programming now!! (While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
    [chandelier.py, color.py, common.py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]
2015-06-06 Wobble & purple functions work correctly
    [chandelier.py, common.py]
2015-06-06 Finished debugging the rainbow/wobble. Improve generator parameter ordering consistency
    [chandelier.py, generator.py]
2015-06-07 Preparing to include stuff into arduino sketch
2015-06-07 Ported code to aduino and it looks like everything should fit!!!
    [led-board.brd, led-board.sch]
2015-06-07 2 patterns work correctly!
    [chandelier.py]
2015-06-08 Fixed unterminated filter chain. Patterns are now repeatable!
    [node.ino]
2015-06-11 Implemented error support with color coding scheme
    [node.ino]
2015-06-11 Implemented speed and fixed transitions.
    [node.ino]
2015-06-11 Some stuff is debugged, but most everything is somewhat broken. :/
    [chandelier.py]
2015-06-11 Debugging, but lots of bugs in transitions.
    [node.ino]
2015-06-14 Fixed old direct drive mode
    [node.ino, source.cpp]
2015-06-23 Fix sin phase to be parametric too
    [generator.py]
2015-06-24 Clamp HSV inputs properly, fix a wrong function pointer call
    [source.cpp]
2015-06-24 Fixed and tested speed setting
    [chandelier.py]
2015-06-25 Stop using millis() and create a calibrated version
2015-06-25 Implemented the C++ side of timer calibration
2015-06-25 Added the server side of timer calibration
2015-06-25 Fix sending entropy to all the nodes
    [chandelier.py]
2015-06-25 Add capacitive touch code
2015-06-26 Implemented color shift filter
2015-06-26 Implemented final stage color filter
2015-06-26 Debugged color filtering
2015-06-26 Debugged color filtering. Still one bug remains in RGB to HSV
    [node.ino, source.cpp]
2015-06-27 Updated fuses and finished coding the calibration stuff
2015-06-28 Fixes for SourceOp and implemented RBGSource
    [common.py, function.py, generator.py]
2015-06-28 Added RGBSource. Added ability to skip a frame. Properly implemented top level filter.
    [node.ino, source.cpp]
2015-06-28 Fix bottle position code
    [node.ino, source.cpp]
2015-06-28 implemented a new time calibration routine that works!
2015-06-28 Improved time calibration
2015-06-28 Ditched color filter and implemented simple brightness
2015-06-28 Added support for the quasi broken color shift filter. Avoid extremes!
2015-06-28 Color shift filter fixes, added fade test
    [function.py]
2015-06-28 Fixed fading between patterns
    [node.ino]
2015-06-29 Minor fix on src op
    [function.py]
2015-06-29 First cut at XYZ source. it compiles!
2015-06-30 Fixed one bug in the XYZ Source
    [generator.py, source.cpp]
2015-07-04 Committing changes from the desert:
    55ab94309cf93387026938f35b86b5d3a23fd02b 19d6c84e2b0a3d63f62f3f931567741c8993bf1f Robert Kaye <rob@musicbrainz.org> 1435874290 +000 commit: Desert hacking!
    19d6c84e2b0a3d63f62f3f931567741c8993bf1f 57783c7ede4a130361c9ac590669f69f0a9afd72 Robert Kaye <rob@musicbrainz.org> 1435882204 +000 commit: Possibly fix it!
    57783c7ede4a130361c9ac590669f69f0a9afd72 01041ae2d82dbe030008152e4dc76a8f78ba0bd2 Robert Kaye <rob@musicbrainz.org> 1435882509 +000 commit: Fixed the bug!
    Whatever those mean. :)
    [generator.py, pattern.py]
2015-07-05 Set up for 6 buttons and recorded mapping
2015-07-05 Finished debugging the relay
2016-01-13 Hopefully final versions of the wood cuts for the flower
2016-01-13 Checking in the cable concentrator schema/layout
    [cable-concentrator.brd, cable-concentrator.sch]
2016-01-17 Trying to fix GenOp, no luck so far. Will work on that later.
    [generator.py]
2016-01-19 Fixed reverse pattern for local angle
    [generator.py]
2016-01-19 Implement reverse circular motion
    [node.ino]
2017-09-07 Checking nearly complete concentrator
    [hippie-trap-concentrator.kicad_pcb, hippie-trap-concentrator.sch]
2017-09-10 Start cleanup, and fixup after core function rewrite
    [chandelier.py, pattern.py]
2017-10-29 Save before ditching arduino.
2017-10-30 non-arduino codebase seems to be working!
2017-11-02 Calibration improvements
2017-11-02 Added a hex file size check to bootloader and made LED error codes sane
2017-11-03 More tweaks, more debugging. Resets from node work, but still don't enter the bootloader
    [chandelier.py]
2017-11-05 Cleaned up error handling.
    [chandelier.py]
2017-11-09 Rework the memory allocation, error patterns and object creation.
    [chandelier.py, common.py]
2017-11-10 Found minor problem in packet receiving code. Now CRC checking works correctly.
    [chandelier.py]
2017-11-10 Rename parse.cpp to pattern.cpp. Fix LED update bugs, errors still not working.
    [source.cpp]
2018-04-16 Fix calibrate script
2018-04-17 Started to implement decay, but the code doesn't seem to work. Interim checkin
    [chandelier.py]
2018-04-17 Implement setting a single LED
2018-04-19 Add panic recovery feature in case bad firmware gets uploaded.
2018-04-20 Program fuses when programming the id
2018-04-23 Finish debugging patterns. Add error pattern, but not hooked up yet.
    [chandelier.py]
2018-04-23 A refactoring of sorts! Interrupt driven serial IO (much faster!) cleanup makefiles to not duplicate source files. compile everything as C++.
2018-05-12 Fix uploding since new interrupt driven serial io
2018-05-26 Tweaking some patterns, adding power on/off support
2018-06-10 Software changes for new SSR power control
2018-06-10 First cut of a clock might do a decent job of indicating seconds.
2018-06-11 Clock is good enough, flashies is now nice and flashy with a new pattern running framework emerging
2018-09-09 Re-work transitions for DJ random. There are common transitions that can be used by patters as it suits them best. Closing transitions can be skipped by passing transition=False to stop().
    [pattern.py, transition.py]
2018-09-11 Wedged the whole trap. Again. Ensure that fuses are programmed, this time around. Also added layer 4(!) and made early layer 4 fixes/improvements.
2019-01-29 First cut of a "texture" pattern
2019-06-26 First cut at py3 version. Loads of bugs!
    [color.py, common.py]
2019-06-27 Finish reworking core enable/disable power on/off code for good mqtt support
    [pattern.py]
2019-07-04 Finish fixing the MQTT integration and add new gradient sweep pattern
    [transition.py]
2021-01-03 Fix pyhon3 uploading and other improvements
    [pattern.py]
2025-02-25 Improve led error codes

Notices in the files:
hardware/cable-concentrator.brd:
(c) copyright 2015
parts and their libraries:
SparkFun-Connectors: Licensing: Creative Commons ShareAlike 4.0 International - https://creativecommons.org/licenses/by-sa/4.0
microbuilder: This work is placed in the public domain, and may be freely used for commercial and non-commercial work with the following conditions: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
